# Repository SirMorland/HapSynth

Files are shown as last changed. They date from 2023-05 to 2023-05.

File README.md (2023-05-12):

# HapSynth

An 8-voice digital substractive synthesizer with motorized slider for haptic feedback.

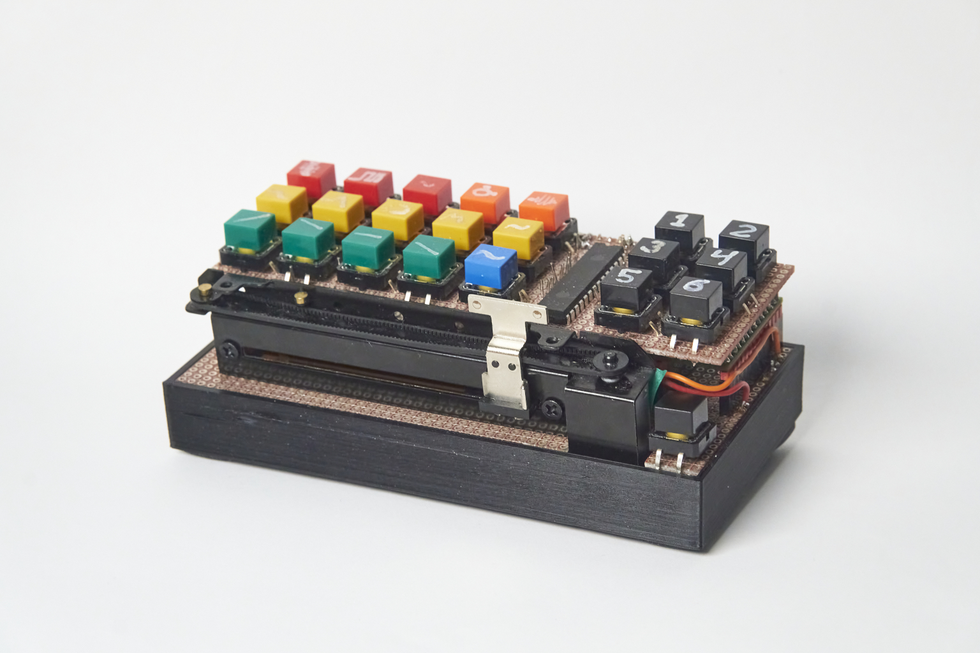
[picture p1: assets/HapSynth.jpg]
HapSynth prototype


## Demo

[https://www.youtube.com/watch?v=hl_LQ_ap-Gw](https://www.youtube.com/watch?v=hl_LQ_ap-Gw)

## Schematics

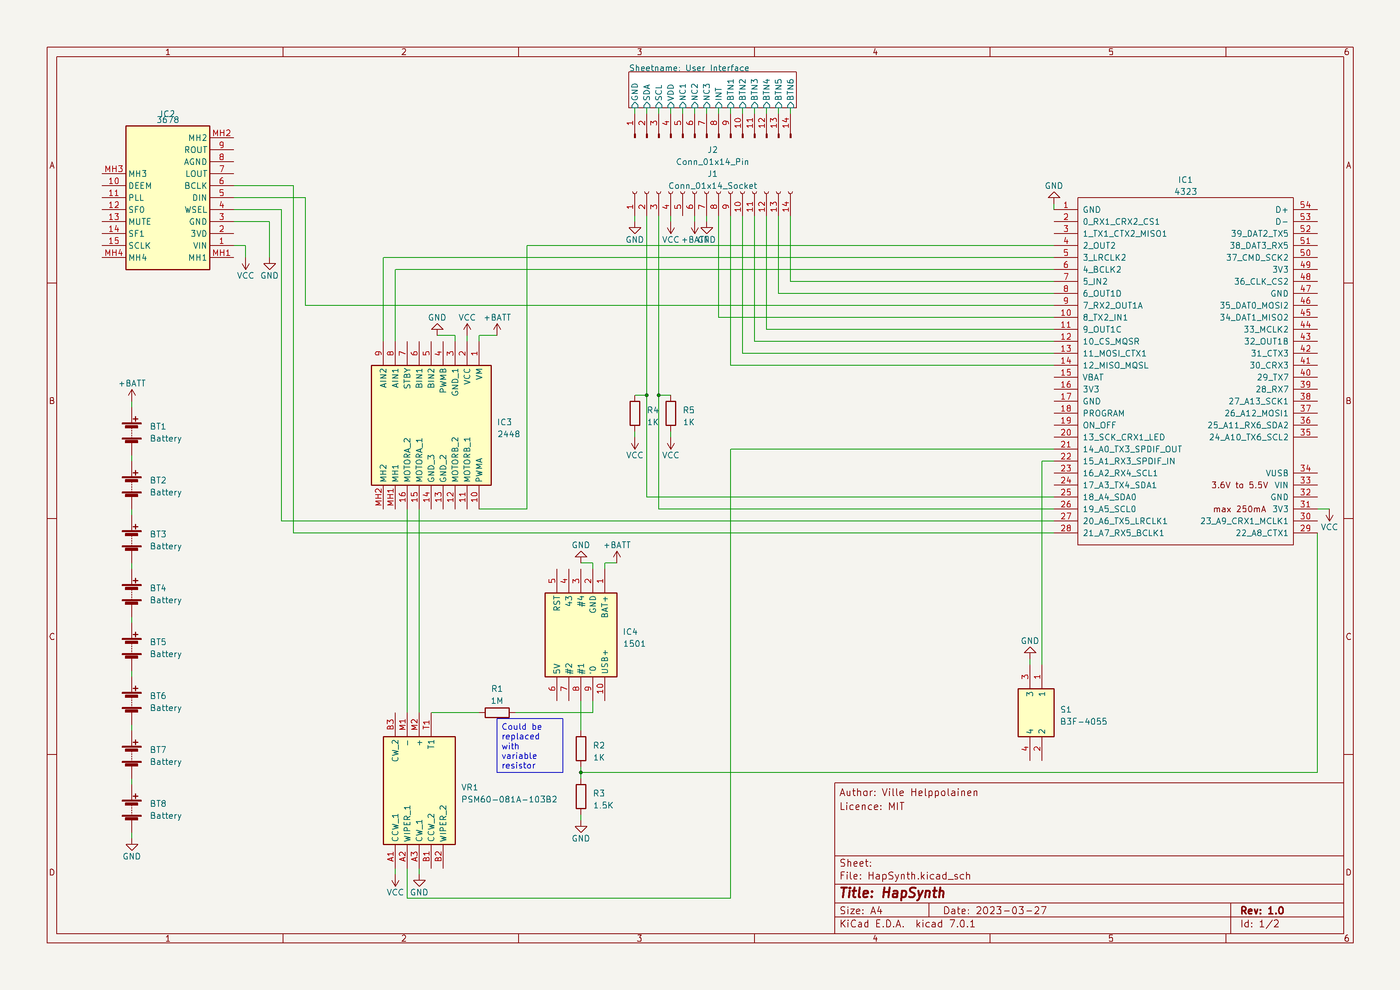
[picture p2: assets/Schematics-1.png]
Schematics for the main board

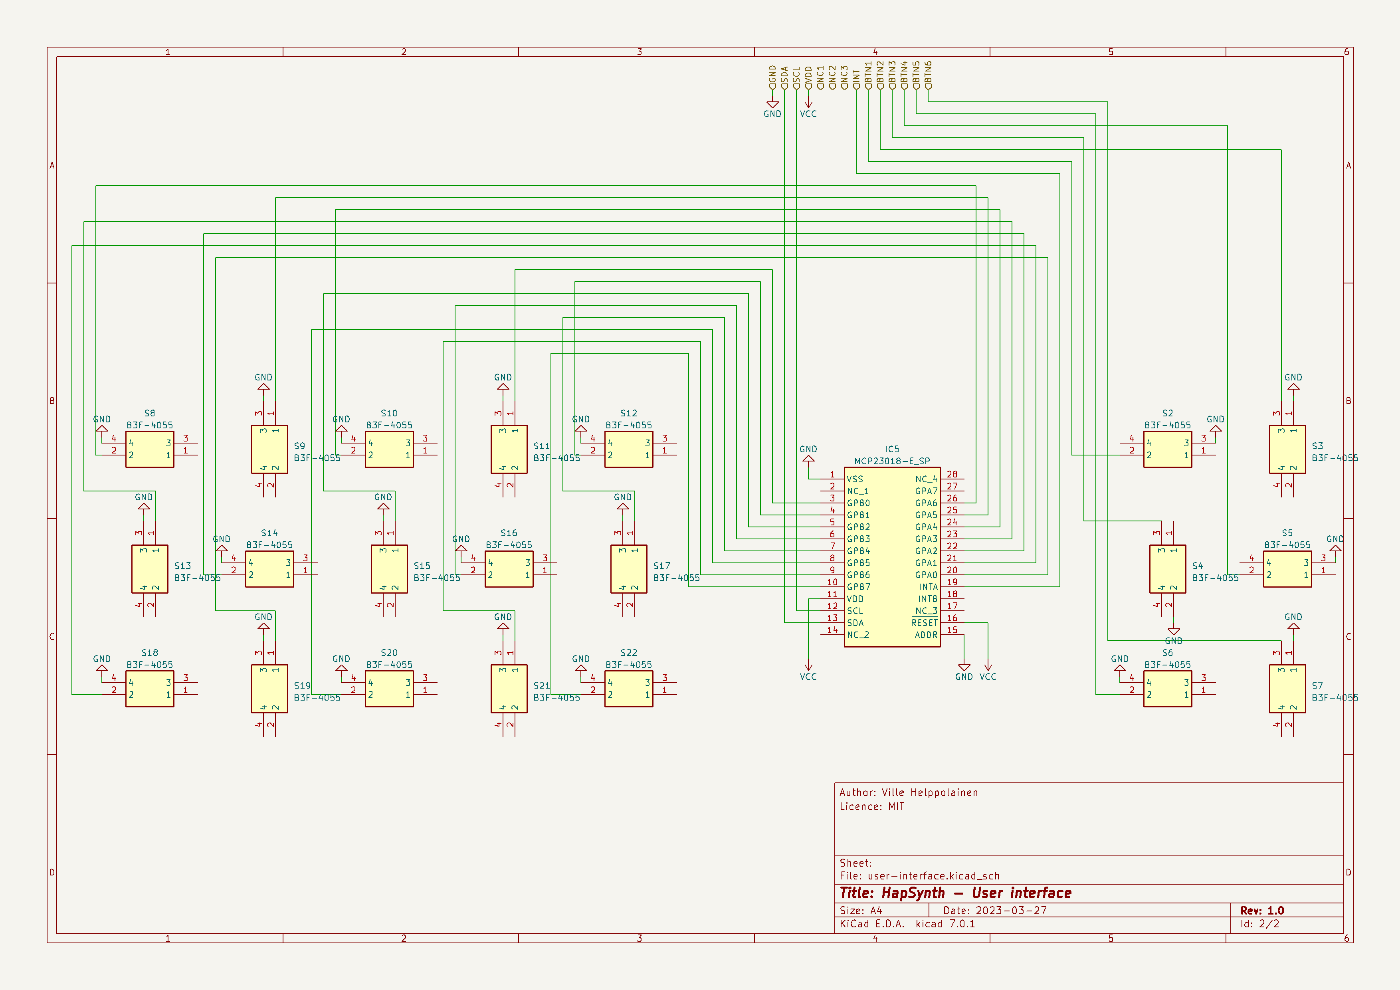
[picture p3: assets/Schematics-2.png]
Schematics for the user interface


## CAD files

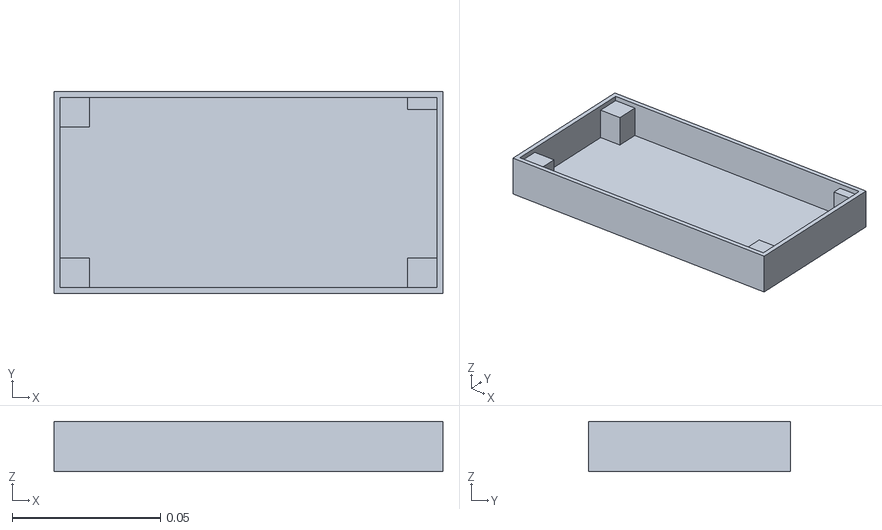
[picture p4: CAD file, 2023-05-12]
stl/case.stl
0.131 x 0.068 x 0.017

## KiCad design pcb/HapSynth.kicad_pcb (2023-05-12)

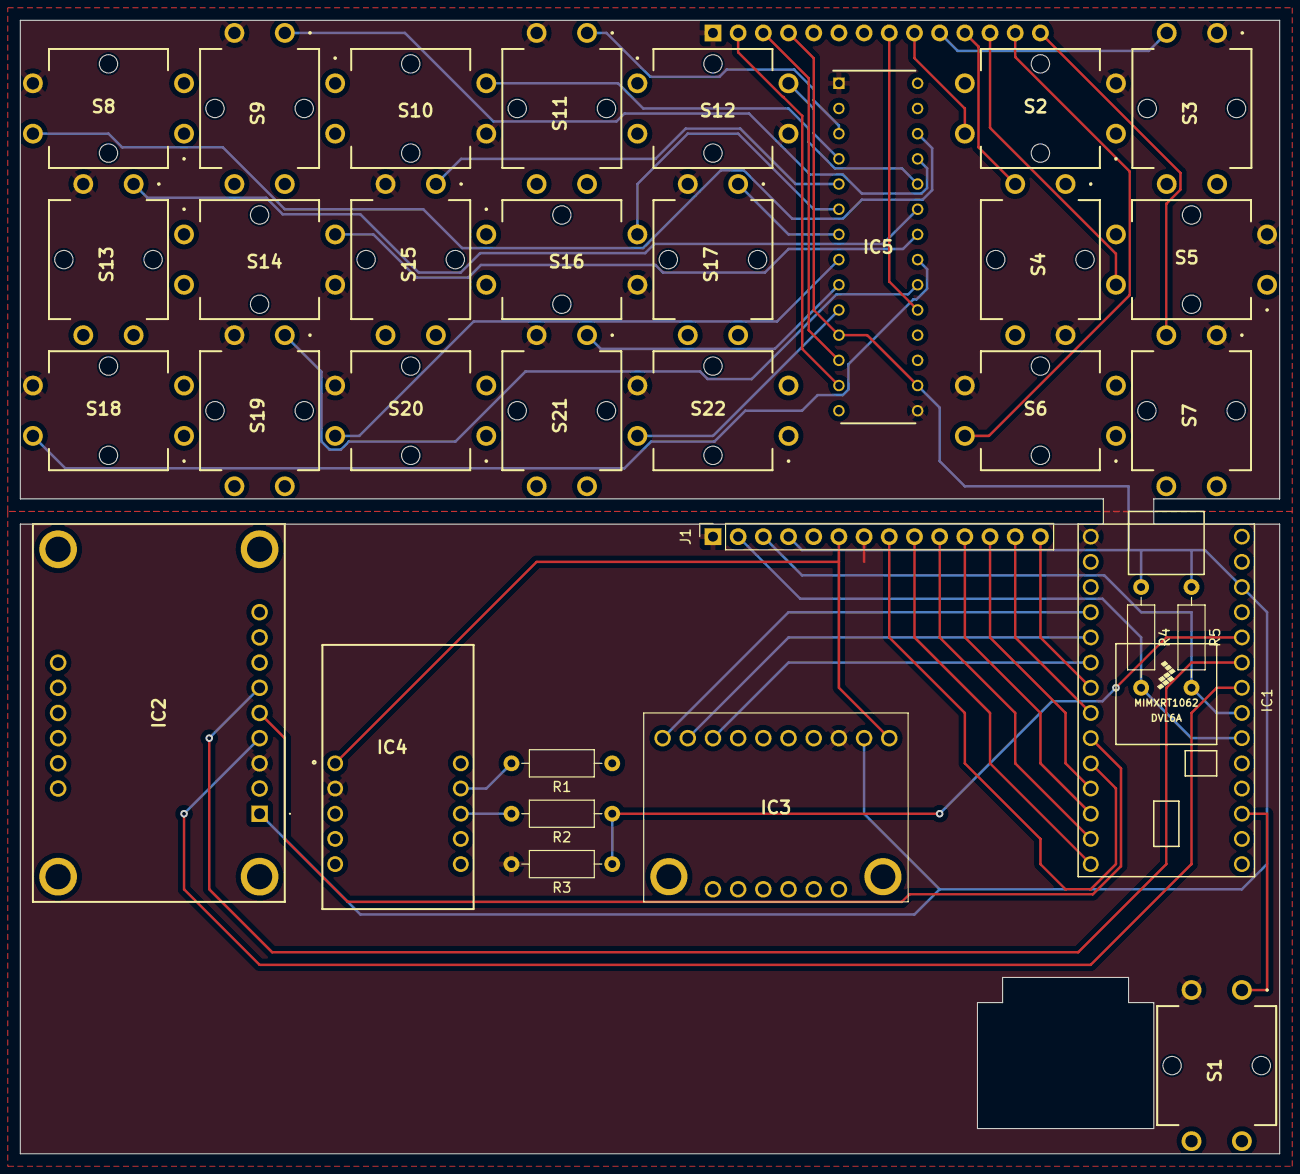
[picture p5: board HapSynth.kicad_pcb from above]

Board: 2 copper layers, 127.0 x 114.3 mm, 34 parts (1 on the bottom side), 46 nets.

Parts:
IC1: 4323; Teensy40-simple
IC2: 3678
IC3: 2448
IC4: 1501
IC5: MCP23018-E_SP; DIP794W56P254L3486H508Q28N
J1: Conn_01x14_Socket; PinSocket_1x14_P2.54mm_Vertical
J2: Conn_01x14_Pin; PinSocket_1x14_P2.54mm_Vertical
R1: 1M; R_Axial_DIN0207_L6.3mm_D2.5mm_P10.16mm_Horizontal
R2, R4, R5: 1K; R_Axial_DIN0207_L6.3mm_D2.5mm_P10.16mm_Horizontal
R3: 1.5K; R_Axial_DIN0207_L6.3mm_D2.5mm_P10.16mm_Horizontal
S1, S2, S3, S4, S5, S6, S7, S8, S9, S10, S11, S12, S13, S14, S15, S16, S17, S18, S19, S20, S21, S22: B3F-4055; B3F-4055-bent

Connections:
+BATT: IC3.1 (VM), IC4.1 (BAT+), J1.6
/Sheetname: User Interface/BTN1: J2.9, S2.2
/Sheetname: User Interface/BTN2: J2.10, S3.3
/Sheetname: User Interface/BTN3: J2.11, S4.3
/Sheetname: User Interface/BTN4: J2.12, S5.2
/Sheetname: User Interface/BTN5: J2.13, S6.2
/Sheetname: User Interface/BTN6: J2.14, S7.3
/Sheetname: User Interface/INT: IC5.19 (INTA), J2.8
/Sheetname: User Interface/SCL: IC5.12 (SCL), J2.3
/Sheetname: User Interface/SDA: IC5.13 (SDA), J2.2
GND: IC1.1 (GND), IC2.3 (GND), IC3.3 (GND_1), IC4.2 (GND), IC5.1 (VSS), IC5.15 (ADDR), J1.1, J1.7, J2.1, R3.2, S1.3, S2.3, S3.1, S4.2, S5.3, S6.4, S7.1, S8.4, S9.3, S10.4, S11.3, S12.4, S13.3, S14.4, S15.3, S16.4, S17.3, S18.4, S19.3, S20.4, S21.3, S22.4
unnamed: IC1.4 (2_OUT2), IC3.10 (PWMA)
unnamed: IC1.5 (3_LRCLK2), IC3.9 (AIN2)
unnamed: IC1.6 (4_BCLK2), IC3.8 (AIN1)
unnamed: IC1.7 (5_IN2), J1.14
unnamed: IC1.8 (6_OUT1D), J1.13
unnamed: IC1.9 (7_RX2_OUT1A), IC2.5 (DIN)
unnamed: IC1.10 (8_TX2_IN1), J1.8
unnamed: IC1.11 (9_OUT1C), J1.12
unnamed: IC1.12 (10_CS_MQSR), J1.11
unnamed: IC1.13 (11_MOSI_CTX1), J1.10
unnamed: IC1.14 (12_MISO_MQSL), J1.9
unnamed: IC1.22 (15_A1_RX3_SPDIF_IN), S1.1
unnamed: IC1.25 (18_A4_SDA0), J1.2, R4.2
unnamed: IC1.26 (19_A5_SCL0), J1.3, R5.2
unnamed: IC1.27 (20_A6_TX5_LRCLK1), IC2.4 (WSEL)
unnamed: IC1.28 (21_A7_RX5_BCLK1), IC2.6 (BCLK)
unnamed: IC1.29 (22_A8_CTX1), R2.1, R3.1
unnamed: IC4.8 (#1), R2.2
unnamed: IC4.9 ('0), R1.2
unnamed: IC5.20 (GPA0), S19.1
unnamed: IC5.21 (GPA1), S18.2
unnamed: IC5.22 (GPA2), S14.2
unnamed: IC5.23 (GPA3), S13.1
unnamed: IC5.24 (GPA4), S10.2
unnamed: IC5.25 (GPA5), S9.1
unnamed: IC5.26 (GPA6), S8.2
unnamed: IC5.3 (GPB0), S11.1
unnamed: IC5.4 (GPB1), S12.2
unnamed: IC5.5 (GPB2), S15.1
unnamed: IC5.6 (GPB3), S16.2
unnamed: IC5.7 (GPB4), S17.1
unnamed: IC5.8 (GPB5), S20.2
unnamed: IC5.9 (GPB6), S21.1
unnamed: IC5.10 (GPB7), S22.2
VCC: IC1.31 (3V3), IC2.1 (VIN), IC3.2 (VCC), IC5.11 (VDD), IC5.16 (~RESET), J1.4, J2.4, R4.1, R5.1

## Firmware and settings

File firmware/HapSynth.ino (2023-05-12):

#include "Synth.h"
#include "SynthParam.h"
#include "HapticMode.h"
#include <EEPROM.h>

// From Hap
#define I2C_ADDRESS 0x20

#define IODIRA		0x00
#define IODIRB		0x01

#define IPOLA		0x02
#define IPOLB		0x03

#define GPINTENA	0x04
#define GPINTENB	0x05

#define DEFVALA		0x06
#define DEFVALB		0x07

#define INTCONA		0x08
#define INTCONB		0x09

#define IOCON		0x0A

#define GPPUA		0x0C
#define GPPUB		0x0D

#define INTFA		0x0E
#define INTFB		0x0F

#define INTCAPA		0x10
#define INTCAPB		0x11

#define GPIOA		0x12
#define GPIOB		0x13

#define EXPANDER_INTERRUPT_PIN 8
#define EXPANDER_INTERRUPT attachInterrupt(digitalPinToInterrupt(EXPANDER_INTERRUPT_PIN), expanderPressed, FALLING);

#define MOTOR_IN1 4
#define MOTOR_IN2 3
#define MOTOR_PWM 2
#define SLIDER    A0

#define BUTTON_1 12
#define BUTTON_2 11
#define BUTTON_3 10
#define BUTTON_4 9
#define BUTTON_5 6
#define BUTTON_6 5
#define BUTTON_SHIFT 15

#define EEPROM_SLIDER_MIN  0
#define EEPROM_SLIDER_MAX  2

void(* resetFunc) (void) = 0;

Synth* synth;
uint32_t synthParamChanged = 0;

int sliderMin = 0;
int sliderMax = 1023;
bool shiftPressed = false;
bool calibrateMin = false;
bool calibrateMax = false;

bool wasTouching = false;

void serialLogPrefix() {
	float mils = millis() / 1000.0f;
	int time = floor(mils);
	mils = round((mils - time) * 1000);
	int seconds = time % 60;
	int minutes = (time - seconds) / 60;

	Serial.print(minutes);
	Serial.print(":");
	if(seconds < 10) {
		Serial.print("0");
	}
	Serial.print(seconds);
	Serial.print(".");
	if(mils < 100) {
		Serial.print("0");
	}
	if(mils < 10) {
		Serial.print("0");
	}
	Serial.print(mils, 0);
	Serial.print(" | ");
}

void serialLog(const char msg[]) {
	serialLogPrefix();
	Serial.println(msg);
}

void serialLogParamName() {
	serialLogPrefix();
	synth->selectedParam->printName();
	Serial.println();
}

void serialLogValuesForThesis() {
	serialLogPrefix();
	
	Serial.print("Cutoff: ");
	Serial.print(String(synth->filterFrequency->rawValue / 1023.0f).c_str());
	
	Serial.print(", Attack: ");
	Serial.print(String(synth->egAttack->rawValue / 1023.0f).c_str());

	Serial.print(", Rate: ");
	Serial.print(String(synth->lfoRate->rawValue / 1023.0f).c_str());

	Serial.print(", LFO amount to PWM: ");
	Serial.print(String(synth->vcoPwmLfoAmount->rawValue / 1023.0f).c_str());

	Serial.print(", Mode: ");
	Serial.print(synth->hapticMode + 1);

	Serial.print(", Param: ");
	synth->selectedParam->printName();

	Serial.println();
}

void initExpander() {
	Wire.beginTransmission(I2C_ADDRESS);
	uint8_t result = Wire.endTransmission();
	if(result == 0) {
		Serial.print("Connected: ");
		Serial.println(I2C_ADDRESS, HEX);
	} else {
		Serial.print("Couldn't connect, please reset...");
	}

	// Reverse input polarity
	transmit(IPOLA, 0xFF);
	transmit(IPOLB, 0xFF);

	// Enable interrupts
	transmit(GPINTENA, 0xFF);
	transmit(GPINTENB, 0xFF);

	// Set interrupt default value
	transmit(DEFVALA, 0x00);
	transmit(DEFVALB, 0x00);

	// Compare interrupts to last value
	transmit(INTCONA, 0x00);
	transmit(INTCONB, 0x00);

	// Mirror INT pins
	transmit(IOCON, 0b01000001);
	
	// Set internal pull-ups to on
	transmit(GPPUA, 0xFF);
	transmit(GPPUB, 0xFF);

	// Reset interrupts
	transmit(INTCAPA);
	Wire.requestFrom(I2C_ADDRESS, 2);
	Wire.read();
	Wire.read();
}

void button1Pressed() {
	if(!shiftPressed) {
		serialLog("Position");
		synth->hapticMode = POSITION;
	} else {
		calibrateMin = true;
	}
}
void button2Pressed() {
	if(!shiftPressed) {
		serialLog("Detents");
		synth->hapticMode = DETENTS;
	} else {
		calibrateMax = true;
	}
}
void button3Pressed() {
	serialLog("Texture");
	synth->hapticMode = TEXTURE;
}
void button4Pressed() {
	serialLog("Friction");
	synth->hapticMode = FRICTION;
}
void button5Pressed() {
	serialLog("Elasticity");
	synth->hapticMode = ELASTICITY;
}
void button6Pressed() {
	if(!shiftPressed) {
		serialLog("Oscillation");
		synth->hapticMode = OSCILLATION;
	} else {
		serialLog("Resetting...");
		synth->reset();
		synthParamChanged = millis();
	}
}
void shiftChanged() {
	int value = digitalRead(BUTTON_SHIFT);
	
	if(value == 0) {
		serialLog("Shift on");
		shiftPressed = true;
	} else {
		serialLog("Shift off");
		shiftPressed = false;
	}
}

void expanderPressed() {
	noInterrupts();
	delayMicroseconds(1000);
	detachInterrupt(digitalPinToInterrupt(EXPANDER_INTERRUPT_PIN));
	interrupts();

	transmit(INTFA);
	Wire.requestFrom(I2C_ADDRESS, 2);
	int flagA = Wire.read();
	int flagB = Wire.read();
	 
	if(flagA != 0) {
		handleInputs(INTCAPA, flagA);
	} else {
		handleInputs(INTCAPB, flagB);
	}

	EXPANDER_INTERRUPT;
}

void handlePreset(uint8_t number) {
	synth->reset();

	switch (number)
	{
		case 1:
			serialLog("Preset 01");
			synth->filterFrequency->update(round(0.6f * 1023));
			break;
		case 2:
			serialLog("Preset 02");
			synth->egAttack->update(round(0.25f * 1023));
			break;
		case 3:
			serialLog("Preset 03");
			synth->lfoRate->update(round(0.4f * 1023));
			synth->vcoPwmLfoAmount->update(round(0.75f * 1023));
			break;
			
		case 4:
			serialLog("Preset 04");
			synth->filterFrequency->update(round(0.4f * 1023));
			break;
		case 5:
			serialLog("Preset 05");
			synth->egAttack->update(round(0.6f * 1023));
			break;
		case 6:
			serialLog("Preset 06");
			synth->lfoRate->update(round(0.75f * 1023));
			synth->vcoPwmLfoAmount->update(round(0.25f * 1023));
			break;
			
		case 7:
			serialLog("Preset 07");
			synth->filterFrequency->update(round(0.25f * 1023));
			break;
		case 8:
			serialLog("Preset 08");
			synth->egAttack->update(round(0.75f * 1023));
			break;
		case 9:
			serialLog("Preset 09");
			synth->lfoRate->update(round(0.6f * 1023));
			synth->vcoPwmLfoAmount->update(round(0.4f * 1023));
			break;
			
		case 10:
			serialLog("Preset 10");
			synth->filterFrequency->update(round(0.75f * 1023));
			break;
		case 11:
			serialLog("Preset 11");
			synth->egAttack->update(round(0.4f * 1023));
			break;
		case 12:
			serialLog("Preset 12");
			synth->lfoRate->update(round(0.25f * 1023));
			synth->vcoPwmLfoAmount->update(round(0.6f * 1023));
			break;
		default:
			break;
	}

	synthParamChanged = millis();
}

void handleInputs(char bank, int flag) {
	transmit(bank);
	Wire.requestFrom(I2C_ADDRESS, 1);
	int cap = Wire.read();

	int value = flag & cap;

	if(value != 0) {
		int n = 0;

		if((flag & B00000001) != 0) n = 1;
		if((flag & B00000010) != 0) n = 2;
		if((flag & B00000100) != 0) n = 3;
		if((flag & B00001000) != 0) n = 4;
		if((flag & B00010000) != 0) n = 5;
		if((flag & B00100000) != 0) n = 6;
		if((flag & B01000000) != 0) n = 7;
		if((flag & B10000000) != 0) n = 8;

		switch(bank) {
			case INTCAPA:
				switch (n) {
					case 1:
						if (!shiftPressed) {
							synth->selectedParam = synth->egDecay;
						} else {
							handlePreset(6);
						}
						break;
					case 2:
						if (!shiftPressed) {
							synth->selectedParam = synth->egAttack;
						} else {
							handlePreset(3);
						}
						break;
					case 3:
						if (!shiftPressed) {
							synth->selectedParam = synth->filterResonance;
						} else {
							handlePreset(5);
						}
						break;
					case 4:
						if (!shiftPressed) {
						synth->selectedParam = synth->filterFrequency;
						} else {
							handlePreset(2);
						}
						break;
					case 5:
						if (!shiftPressed) {
							synth->selectedParam = synth->vcoPwmLfoAmount;
						} else {
							handlePreset(7);
						}
						break;
					case 6:
						if (!shiftPressed) {
							synth->selectedParam = synth->vcoPwm;
						} else {
							handlePreset(4);
						}
						break;
					case 7:
						if (!shiftPressed) {
							synth->selectedParam = synth->vcoFrequency;
						} else {
							handlePreset(1);
						}
						break;
					case 8:
						break;
					default:
						break;
				}
				break;
			case INTCAPB:
				switch (n) {
					case 1:
						if (!shiftPressed) {
							synth->selectedParam = synth->mixerSub;
						} else {
							handlePreset(10);
						}
						break;
					case 2:
						synth->selectedParam = synth->mixerNoise;
						break;
					case 3:
						if (!shiftPressed) {
							synth->selectedParam = synth->filterDrive;
						} else {
							handlePreset(8);
						}
						break;
					case 4:
						if (!shiftPressed) {
							synth->selectedParam = synth->filterEGAmount;
						} else {
							handlePreset(11);
						}
						break;
					case 5:
						synth->selectedParam = synth->filterLFOAmount;
						break;
					case 6:
						if (!shiftPressed) {
							synth->selectedParam = synth->egSustain;
						} else {
							handlePreset(9);
						}
						break;
					case 7:
						if (!shiftPressed) {
							synth->selectedParam = synth->egRelease;
						} else {
							handlePreset(12);
						}
						break;
					case 8:
						synth->selectedParam = synth->lfoRate;
						break;
					default:
						break;
				}
				break;
			default:
				break;

		}

		if(n != 0  && !shiftPressed) {
			serialLogParamName();
			synthParamChanged = millis();
		}
	}
}

void transmit(int reg) {
	Wire.beginTransmission(I2C_ADDRESS);
	Wire.write(reg);
	Wire.endTransmission();
}

void transmit(int reg, int data) {
	Wire.beginTransmission(I2C_ADDRESS);
	Wire.write(reg);
	Wire.write(data);
	Wire.endTransmission();
}

void OnNoteOn(uint8_t channel, uint8_t note, uint8_t velocity) {
	synth->onNoteOn(channel, note, velocity);
}

void OnNoteOff(uint8_t channel, uint8_t note, uint8_t velocity) {
	synth->onNoteOff(channel, note, velocity);
}

void OnPitchChange(uint8_t channel, int pitch) {
	synth->onPitchChange(channel, pitch);
}

void OnProgramChange(uint8_t channel, uint8_t program) {
	serialLog("Program Change Received");
	handlePreset(program);
}

void writeToEeprom(int address, int value) {
	EEPROM.write(address, value >> 8);
	EEPROM.write(address + 1, value & 0xFF);
}
int readFromEeprom(int address) {
	return (EEPROM.read(address) << 8) + EEPROM.read(address + 1);
}

void setup() {
	Serial.begin(9600);
	Wire.begin();

	// Set pin modes
	pinMode(MOTOR_IN1, OUTPUT);
	pinMode(MOTOR_IN2, OUTPUT);
	pinMode(MOTOR_PWM, OUTPUT);

	pinMode(BUTTON_1, INPUT_PULLUP);
	pinMode(BUTTON_2, INPUT_PULLUP);
	pinMode(BUTTON_3, INPUT_PULLUP);
	pinMode(BUTTON_4, INPUT_PULLUP);
	pinMode(BUTTON_5, INPUT_PULLUP);
	pinMode(BUTTON_6, INPUT_PULLUP);
	pinMode(BUTTON_SHIFT, INPUT_PULLUP);

	attachInterrupt(digitalPinToInterrupt(BUTTON_1), button1Pressed, FALLING);
	attachInterrupt(digitalPinToInterrupt(BUTTON_2), button2Pressed, FALLING);
	attachInterrupt(digitalPinToInterrupt(BUTTON_3), button3Pressed, FALLING);
	attachInterrupt(digitalPinToInterrupt(BUTTON_4), button4Pressed, FALLING);
	attachInterrupt(digitalPinToInterrupt(BUTTON_5), button5Pressed, FALLING);
	attachInterrupt(digitalPinToInterrupt(BUTTON_6), button6Pressed, FALLING);
	attachInterrupt(digitalPinToInterrupt(BUTTON_SHIFT), shiftChanged, CHANGE);

	pinMode(EXPANDER_INTERRUPT_PIN, INPUT);
	EXPANDER_INTERRUPT;
	
	initExpander();

	synth = new Synth();

	usbMIDI.setHandleNoteOff(OnNoteOff);
	usbMIDI.setHandleNoteOn(OnNoteOn);
	usbMIDI.setHandlePitchChange(OnPitchChange);
	usbMIDI.setHandleProgramChange(OnProgramChange);

	pinMode(LED_BUILTIN,OUTPUT);
	synthParamChanged = millis();

	sliderMin = readFromEeprom(EEPROM_SLIDER_MIN);
	sliderMax = readFromEeprom(EEPROM_SLIDER_MAX);
}

void loop() {
	usbMIDI.read();

	int value = analogRead(SLIDER);

	if(calibrateMin) {
		serialLog("Calibrating min...");
		digitalWrite(LED_BUILTIN, HIGH);

		int values = 0;
		for(int i = 0; i < 10; i++) {
			values += analogRead(SLIDER);
		}
		sliderMin = values / 10;
		writeToEeprom(EEPROM_SLIDER_MIN, sliderMin);

		digitalWrite(LED_BUILTIN, LOW);
		Serial.print("Calibration done, new min: ");
		Serial.println(sliderMin);

		calibrateMin = false;
	} else if(calibrateMax) {
		serialLog("Calibrating max...");
		digitalWrite(LED_BUILTIN, HIGH);

		int values = 0;
		for(int i = 0; i < 10; i++) {
			values += analogRead(SLIDER);
		}
		sliderMax = values / 10;
		writeToEeprom(EEPROM_SLIDER_MAX, sliderMax);

		digitalWrite(LED_BUILTIN, LOW);
		Serial.print("Calibration done, new max: ");
		Serial.println(sliderMax);

		calibrateMax = false;
	} else {
		value = map(value, sliderMin, sliderMax, 0, 1023);

		if(millis() - synthParamChanged > 100) {
			bool touching = digitalRead(22);

			synth->selectedParam->update(value);
			synth->selectedParam->hapticModes[synth->hapticMode]->update(value, touching);
			
			
			if (wasTouching && !touching) {
				serialLogValuesForThesis();
			}
			wasTouching = touching;
			
		} else {
			value -= synth->selectedParam->rawValue;

			if(value > 8) {
				digitalWrite(MOTOR_IN1, LOW);
				digitalWrite(MOTOR_IN2, HIGH);
				analogWrite(MOTOR_PWM, map(value, 0, 1023 - synth->selectedParam->rawValue, 128, 256));
			} else if (value < -8) {
				digitalWrite(MOTOR_IN1, HIGH);
				digitalWrite(MOTOR_IN2, LOW);
				analogWrite(MOTOR_PWM, map(-value, 0, synth->selectedParam->rawValue, 128, 256));
			} else {
				analogWrite(MOTOR_PWM, 0);
			}
		}
	}
}

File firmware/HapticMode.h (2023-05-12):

#pragma once

#define MOTOR_IN1 4
#define MOTOR_IN2 3
#define MOTOR_PWM 2

enum HAPTIC_MODE {
	POSITION = 0,
	DETENTS = 1,
	TEXTURE = 2,
	FRICTION = 3,
	ELASTICITY = 4,
	OSCILLATION = 5
};

class HapticMode {
	public:
		virtual void update(int position, bool touching);
};

class Position : public HapticMode {
	public:
		Position() { }
		void update(int position, bool touching) override {
			analogWrite(MOTOR_PWM, 0);
		}
};

class Elasticity : public HapticMode {
	public:
		Elasticity(int* center) {
			this->center = center;
		}

		void update(int position, bool touching) override {
			position -= *center;

			if(position > 8) {
				digitalWrite(MOTOR_IN1, LOW);
				digitalWrite(MOTOR_IN2, HIGH);
				analogWrite(MOTOR_PWM, map(position, 0, 1023 - *center, 64, 256));
			} else if (position < -8) {
				digitalWrite(MOTOR_IN1, HIGH);
				digitalWrite(MOTOR_IN2, LOW);
				analogWrite(MOTOR_PWM, map(-position, 0, *center, 64, 256));
			} else {
				analogWrite(MOTOR_PWM, 0);
			}
		}
	
	private:
		int* center;
};

class Detents : public HapticMode {
	public:
		Detents(int detents) {
			this->detentSize = 1024.0f / (detents - 1);
			this->halfDetent = this->detentSize / 2.0f;
		}

		void update(int position, bool touching) override {
			float notch = round(position / this->detentSize) * this->detentSize;
			float min = constrain(notch - this->halfDetent, 0, 1023);
			float max = constrain(notch + this->halfDetent, 0, 1023);

			if(position > notch + 16) {
				digitalWrite(MOTOR_IN1, LOW);
				digitalWrite(MOTOR_IN2, HIGH);
				analogWrite(MOTOR_PWM, map(position, notch, max, 192, 64));
			} else if(position < notch - 16) {
				digitalWrite(MOTOR_IN1, HIGH);
				digitalWrite(MOTOR_IN2, LOW);
				analogWrite(MOTOR_PWM, map(position, min, notch, 64, 192));
			} else {
				analogWrite(MOTOR_PWM, 0);
			}
		}

	private:
		float detentSize;
		float halfDetent;
};

class Texture : public HapticMode {
	public:
		Texture() { }

		void update(int position, bool touching) override {
			int direction = ((int)roundf(millis() / 5.0f)) % 2;
			int distance = abs(position - previousPosition);
			previousPosition = previousPosition * 0.99f + position * 0.01f;

			if(distance > 1.0f) {
				float vibration = constrain(distance * 4, 32, 255);
				if(direction > 0) {
					digitalWrite(MOTOR_IN1, LOW);
					digitalWrite(MOTOR_IN2, HIGH);
					analogWrite(MOTOR_PWM, vibration);
				} else {
					digitalWrite(MOTOR_IN1, HIGH);
					digitalWrite(MOTOR_IN2, LOW);
					analogWrite(MOTOR_PWM, vibration);
				}
			} else {
				analogWrite(MOTOR_PWM, 0);
			}
		}

	private:
		float previousPosition = 0;
};

class Oscillation : public HapticMode {
	public:
		Oscillation(int* center) {
			this->center = center;
		}

		void update(int position, bool touching) override {
			if(touching) {
				displacement = abs(position - *center) * damping;
				direction = position > *center ? 1 : -1;
				analogWrite(MOTOR_PWM, 0);
			} else {
				if(displacement > 8) {
					if(direction > 0) {
						if(position < *center - displacement || position < 8) {
							direction = -1;
							displacement *= damping;
						}
					} else if(direction < 0) {
						if(position > *center + displacement || position > 1023 - 8) {
							direction = 1;
							displacement *= damping;
						}
					}
					
					int speed = map(displacement, 0, 1023, 64, 255);

					if(direction > 0) {
						digitalWrite(MOTOR_IN1, LOW);
						digitalWrite(MOTOR_IN2, HIGH);
						analogWrite(MOTOR_PWM, speed);
					} else if (direction < 0) {
						digitalWrite(MOTOR_IN1, HIGH);
						digitalWrite(MOTOR_IN2, LOW);
						analogWrite(MOTOR_PWM, speed);
					}
				} else {
					analogWrite(MOTOR_PWM, 0);
				}
			}
		}

	private:
		int* center;

		int8_t direction = 0;
		float displacement = 0.0f;
		float damping = 0.75f;
};

class Friction : public HapticMode {
	public:
		Friction() { }

		void update(int position, bool touching) override {
			int direction = position - previousPosition;
			previousPosition = previousPosition * 0.99f + position * 0.01f;
			
			int val = map(min(abs(direction), 255), 0, 255, 255, 0);

			if(touching) {
				if(direction > 2) {
					digitalWrite(MOTOR_IN1, LOW);
					digitalWrite(MOTOR_IN2, HIGH);
					analogWrite(MOTOR_PWM, val);
				} else if(direction < -2) {
					digitalWrite(MOTOR_IN1, HIGH);
					digitalWrite(MOTOR_IN2, LOW);
					analogWrite(MOTOR_PWM, val);
				} else {
					analogWrite(MOTOR_PWM, 0);
				}
			} else {	
				analogWrite(MOTOR_PWM, 0);
			}
		}

	private:
		float previousPosition = 0;
		uint32_t previousTime = 0;
};

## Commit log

2023-05-12 feat: Add KiCad files
    [HapSynth.kicad_pcb, HapSynth.kicad_sch, user-interface.kicad_sch]
2023-05-12 feat: Add case 3D-model
    [case.stl]
2023-05-12 feat: Add schematics to README

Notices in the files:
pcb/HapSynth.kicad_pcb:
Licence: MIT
